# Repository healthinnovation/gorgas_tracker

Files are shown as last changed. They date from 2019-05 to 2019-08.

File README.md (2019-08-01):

# GORGAS tracker - Project: Malaria and Human Mobility in the Peruvian Amazon

The GORGAS tracker is an open-source GPS tracker developed by the [Health Innovation Lab](https://imtavh.cayetano.edu.pe/en/research/labs/health-innovation-laboratory.html) from The Institute of Tropical Medicine "Alexander von Humboldt". The GPS tracker was developed and used in a cohort study to investigate the role of human population movement in malaria epidemiology in rural villages in the Peruvian Amazon river networks.

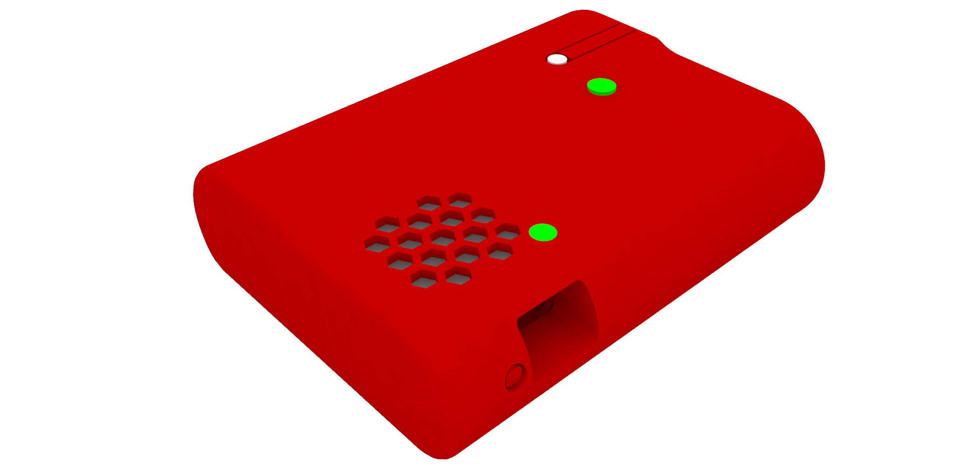
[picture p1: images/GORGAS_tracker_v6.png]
GORGAS tracker 3D model


The GORGAS tracker is based on the [Rephone](http://wiki.seeedstudio.com/RePhone/) platform (SeeedStudio) and has the following characteristics:
* Long-life battery
* Stores GPS coordinates and timestamp
* Sets a buffer area and report if a participant move outside that boundary
* Locks the interaction with the participant
* Easy set-up during fieldwork using a laptop/tablet (visual interface)

Are you ready to build your own GORGAS tracker?
* Hardware: Bill of materials and STL files
* Scripts: GORGAS tracker algorithms
* Visual Interface: PC/Tablet Visual Interface

Visualizacion_Mov

***Understanding the relationship between malaria transmission and human mobility in diverse endemic settings is key for designing and implementing locally adapted and sustainable control and elimination strategies*** (Rosa-Aguirre et al., 2017).

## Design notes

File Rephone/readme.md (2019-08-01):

# GORGAS tracker scripts
This repository contains the scripts that run the GORGAS tracker. This device is based on [Rephone Geo Kit](https://www.seeedstudio.com/RePhone-Geo-Kit-p-2624.html). Rephone is an open source modular phone that supports different integrated development environments (IDE): Lua, Javascript, Arduino IDE and Eclipse IDE. Our team worked with Arduino IDE.

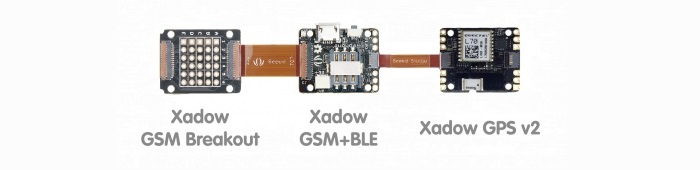
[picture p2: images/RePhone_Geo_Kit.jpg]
RephoneGeoKit


## Before you start
We recommend you to visit [Rephone wiki documentation](http://wiki.seeedstudio.com/RePhone/). There you will find information about [Arduino IDE for Rephone](http://wiki.seeedstudio.com/Arduino_IDE_for_RePhone_Kit/) version which contains the libraries you need to upload the code. Also you can go directly to SeeedStudio Github repository and download the [Arduino IDE](https://github.com/Seeed-Studio/Arduino_IDE_for_RePhone).

**Note:** The Arduino IDE for Rephone is only available for Windows XP/Vista/⅞/8.1. Other versions soon. 

## Scripts
Algorithms are based on three tasks: **GPS files reading**, **Power Management**, and **GPS-tracking logs**. GPS files contain the data and medata divided in four plain text files (.txt):
* locations.txt: GPS coordinates, timestamp, number of satellites, battery life status, and quality of the GPS signal
* id.txt: participant ID and location status (to identify and report if a participant move outside that boundary)
* perimeter.txt: centroid and radius of the community (to set a buffer area)
* time.txt: time interval and time for active and sleep modes

### Workflow
- **GPS files reading:** starts with algorithm reading the id file to switch the led (red or green) on as an initial state. Then, the time file is read to set up times for power management and the time interval for tracking.
- **Power management:** configures internal time and date variables from GPS data received. The code is always comparing the internal clock and date with the time and date collected from satellites system. If variables are correct, power management allows the control module to collect location and store data on the locations file. Power mode (time file) is read by the power management to switch data logger off or restore its operations.
- **GPS-tracking logs:** collects participants location during the follow-up and constantly verify if a participant is outside the village boundary. As result update the location status in the id file. 

We developed two script versions:
- Simplified version: Gorgas_Simplificado.ino 
- Extended version: Gorgas_Final.ino

The simplified version of the script is based on functions and to modify the code is easier than the extended version. 

**Note:** You must check [Xadow GSM+BLE](http://wiki.seeedstudio.com/RePhone_Lumi_Kit/#xadow-gsmble) specifications and libraries first, if you want to modify the scripts.

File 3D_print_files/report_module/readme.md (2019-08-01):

## Reporting module
In order to inspect the report of whether the participant had moved outside the boundaries of the community, a new module (RGB led and one button) and algorithm were designed. This reporting module was coupled to the extension module allowing interaction with the control module. 

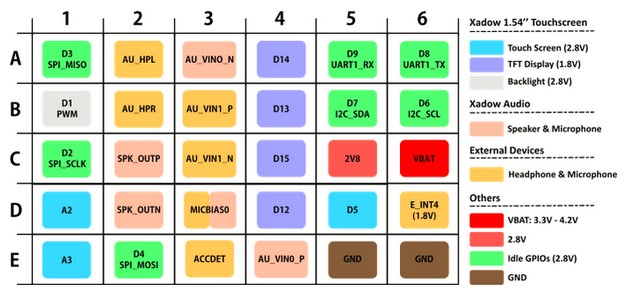
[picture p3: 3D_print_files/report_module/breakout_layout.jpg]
breakout_distribution


The colors distribution was red when the participant moved outside the boundaries, green when they were not registered movement outside the boundaries, and blue when incorrect GPS data was recorded at initialization. The button interaction distribution was one tap to verify whether the participant moved outside the boundary (red or green), and two taps to verify the correct initialization (blue).

### Electronic components
- Button (x1)
- RGB LED 5050 (x1)
- RES 330Ohm SMD (x1)
- Male pins (x5)

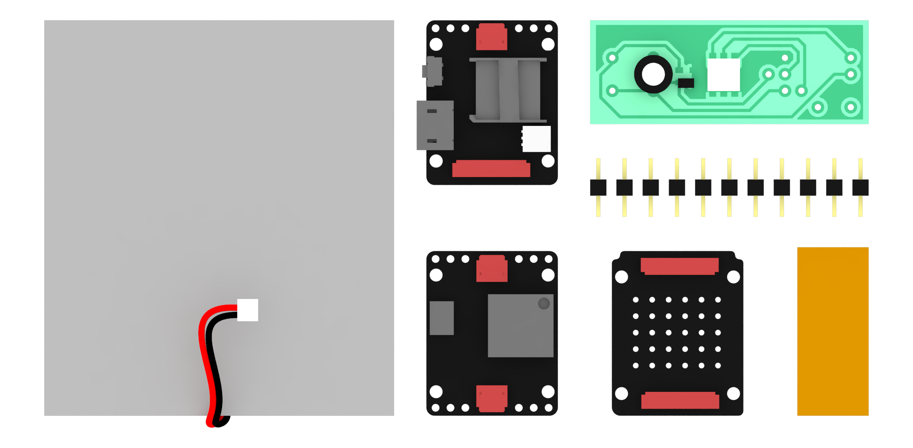
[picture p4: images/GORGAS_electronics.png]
electronics


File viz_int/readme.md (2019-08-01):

# GORGAS tracker visual interface v1.0
A graphic interface was developed on Visual Studio to visualize the datasets in a comprehensive way. The initial view was a menu with three options: GPS-tracker configuration, Map configuration and Data analysis. **Note:** The visual interface is only available in Spanish. English version soon.

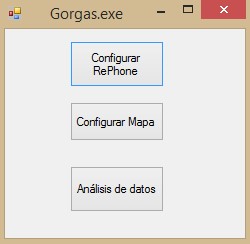
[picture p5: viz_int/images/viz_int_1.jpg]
main


GPS-tracker configuration was a section where user should select the connected device to upload a new configuration. This option has two ways to configure data loggers: default configuration and customized configuration. Default configuration has data from the last default or customized configuration. Customized configuration allows user to modify ID, latitude, longitude, radius of buffer (meters), time interval, active mode (time), and sleep mode (time).

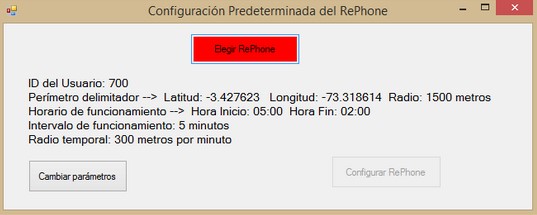
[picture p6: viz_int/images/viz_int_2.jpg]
configuration1


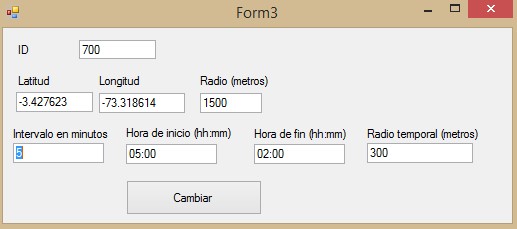
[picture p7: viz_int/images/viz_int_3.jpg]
configuration2


Map configuration was a section to store offline Google maps. Users had to select a specific area (e.g. province of Maynas) and then they could download the map with Internet and store it to computer memory. These maps were useful for data analysis in the field where connectivity is limited. 

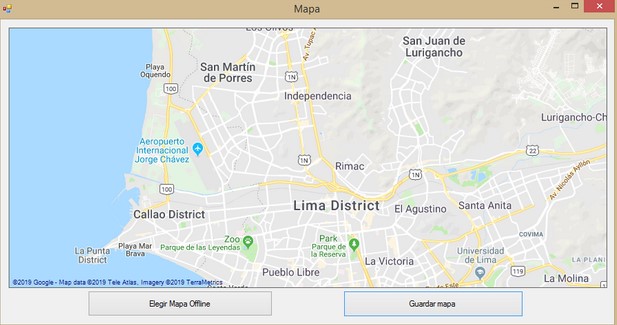
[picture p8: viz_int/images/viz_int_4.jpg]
map


The last option was Data analysis, a section to perform a preview data analysis on the field. Users could upload all GPS files on the graphic interface and they would see the offline map with location points stored and the GPS-tracker configuration. According research team needs, it was developed a functionality to simulate participants’ travels based on tracking data. The graphic interface proposed in this study is more suitable to field studies than traditional GIS software (e.g. preview datasets analysis or following study progression) but it doesn’t replace GIS for complex analysis.

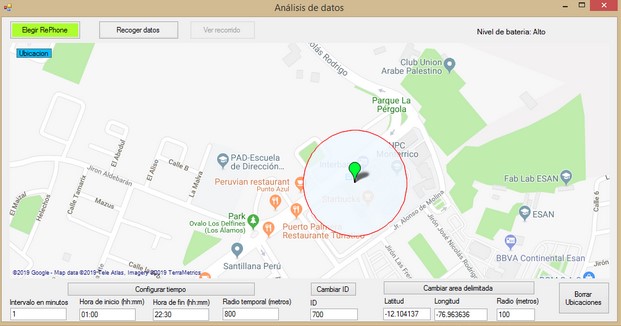
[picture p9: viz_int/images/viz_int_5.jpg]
data_analysis1


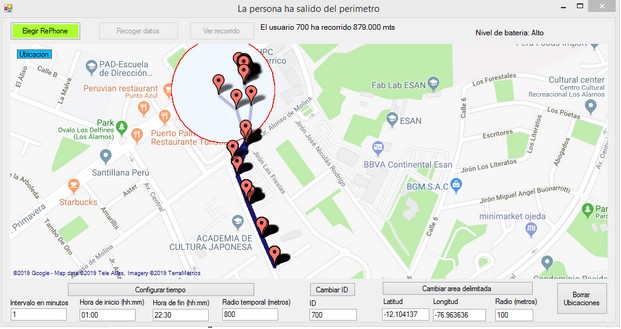
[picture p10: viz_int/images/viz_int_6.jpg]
data_analysis2


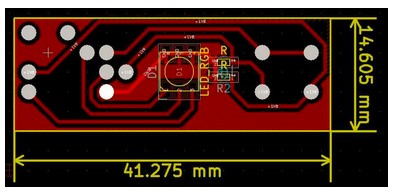
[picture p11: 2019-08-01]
3D_print_files/report_module/PCB_KiCAD.jpg

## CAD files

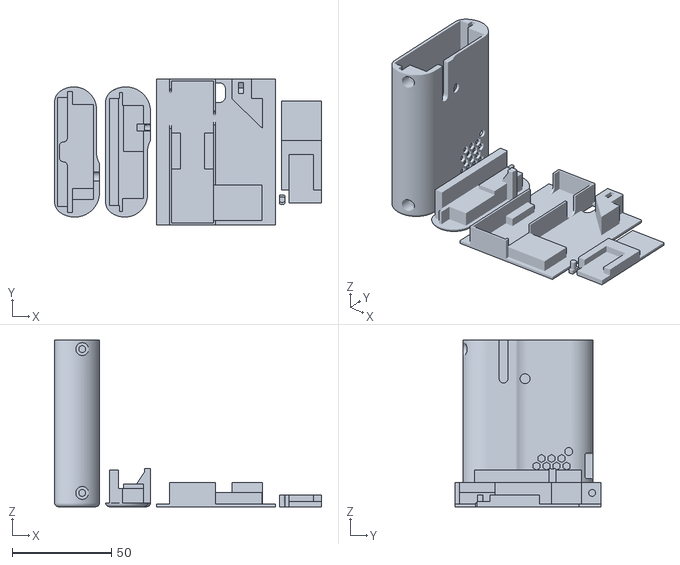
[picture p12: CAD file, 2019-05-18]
3D_print_files/Malaria v6.0.stl
134.8 x 73.8 x 84.1

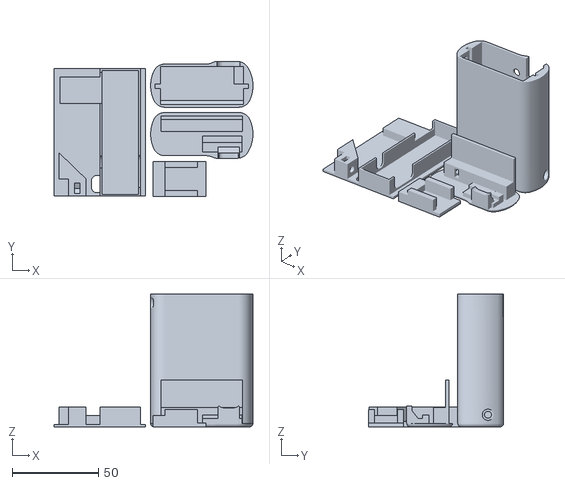
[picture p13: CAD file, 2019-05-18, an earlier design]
3D_print_files/Malaria v5.0.stl
115.2 x 78.2 x 76.8

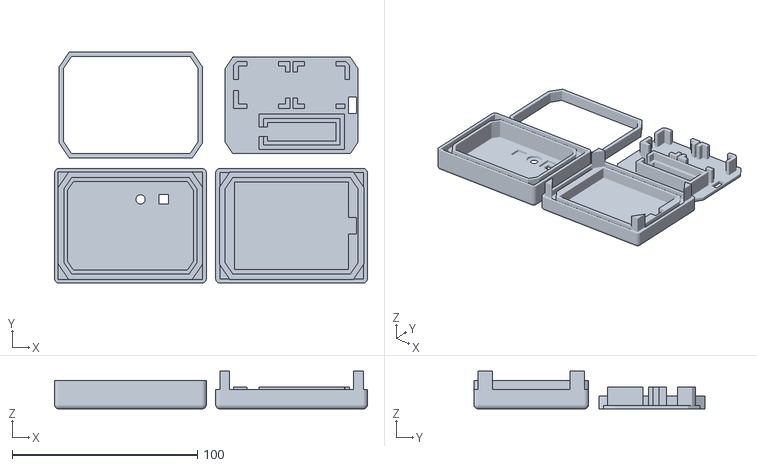
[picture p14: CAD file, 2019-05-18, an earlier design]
3D_print_files/Malaria v2.0.stl
169.0 x 124.9 x 20.5

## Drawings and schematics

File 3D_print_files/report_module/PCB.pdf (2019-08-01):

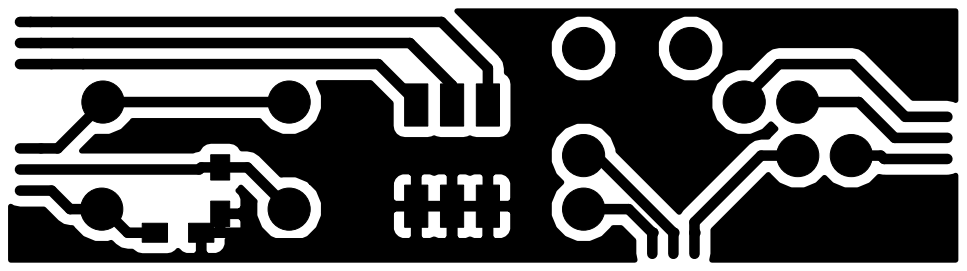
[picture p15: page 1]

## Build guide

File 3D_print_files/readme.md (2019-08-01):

# GORGAS tracker STL files
This folder is for STL files that have been compiled through the build process. Here you will find different GORGAS tracker versions that we think you could use them for other applications. 3D printed parts have been carefully designed to print reliably on most RepRap-style printers, without support material or adhesion layer. If your printer has a standard-sized bed (180mmx180mm should be fine) then it's possible to print the complete GORGAS tracker.

_Version 6.0 (65.73x22.75x86.10mm) was the last design and it was tested on urban and rural settings from Iquitos, Loreto (Peru)_

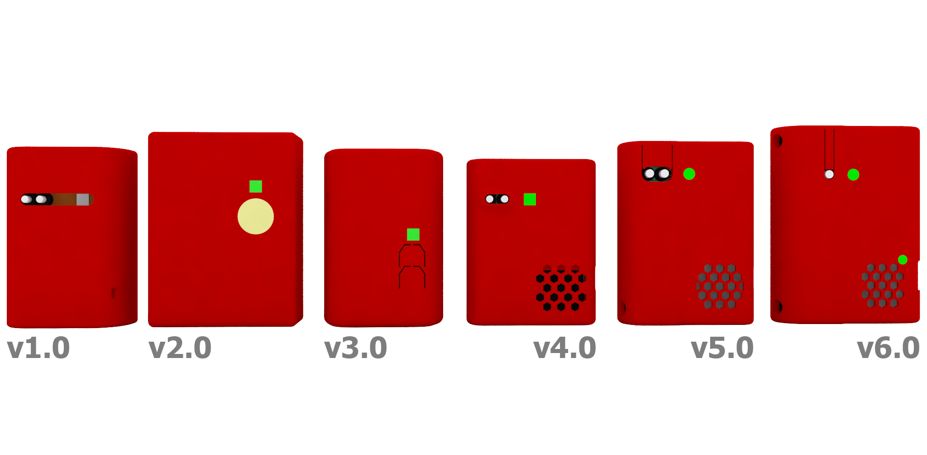
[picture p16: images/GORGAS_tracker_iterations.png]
GORGAS_tracker_iterations


## Print settings
* **3D Printer model:** Prusa i3 (reference)
* **Layer size:** 0.2mm
* **Adhesion type:** Brim (optional)
* **Support type:** None
* **Infill Density:** 30%
* **Filament:** PLA/ABS

STL_animation

## Bill of materials
* Rephone Geo Kit + Reporting module (x1)
* 3D printed parts set (x1)
* Li-Po battery 2500mAh (x1)
* M3 12mm screws (x2)
* M3 nuts (x2)

## Hardware assembly
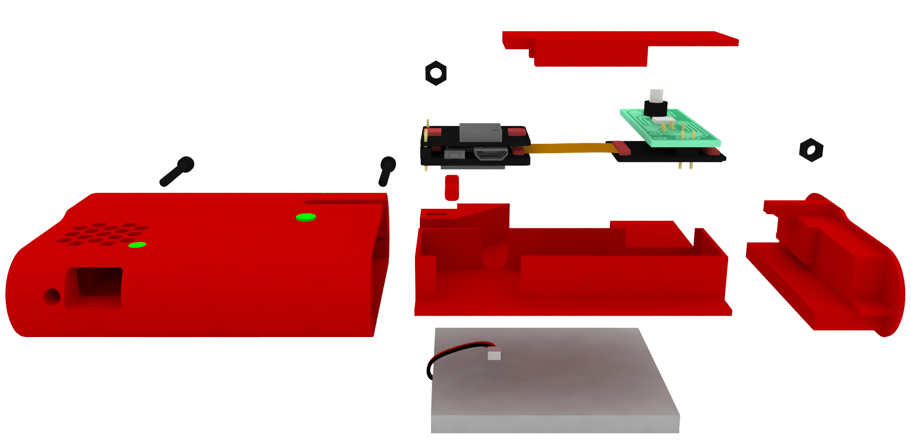
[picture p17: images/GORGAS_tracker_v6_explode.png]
GPS_explode


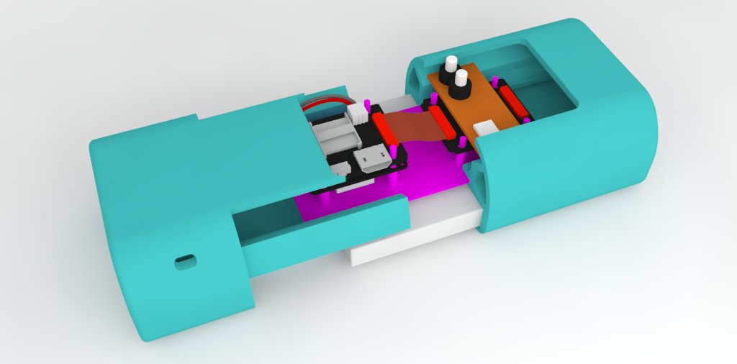
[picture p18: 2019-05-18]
3D_print_files/Malaria v1.0.jpg

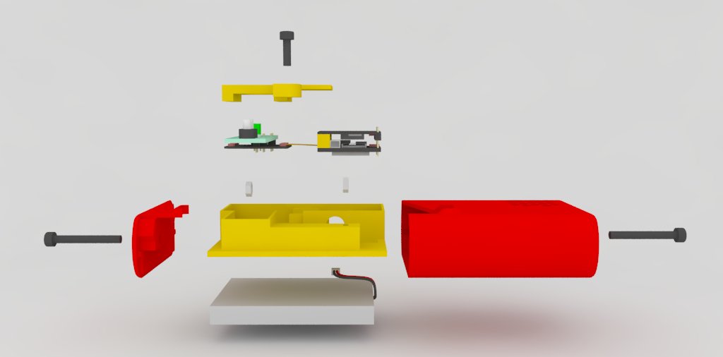
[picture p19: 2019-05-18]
3D_print_files/Malaria v4.0.jpg

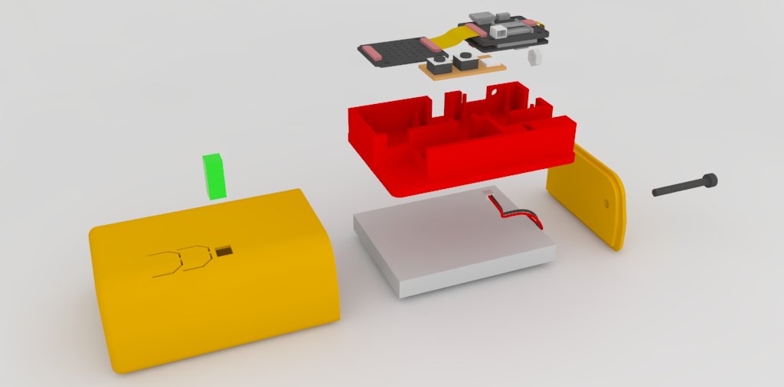
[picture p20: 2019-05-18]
3D_print_files/Malaria v3.0.jpg

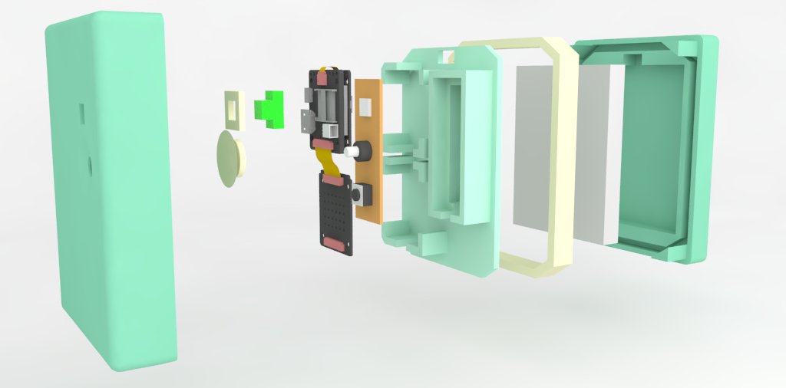
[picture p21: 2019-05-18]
3D_print_files/Malaria v2.0.jpg

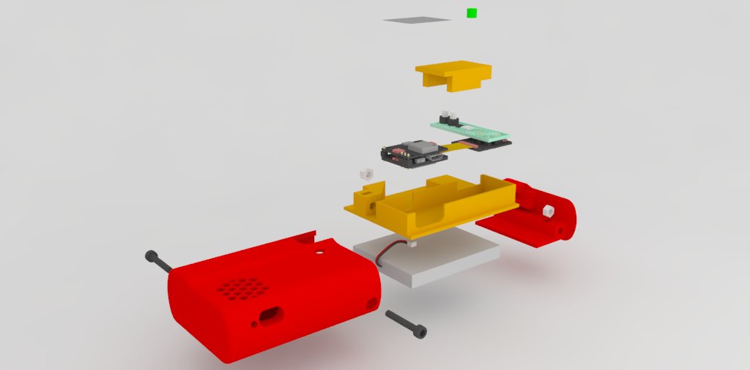
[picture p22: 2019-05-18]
3D_print_files/Malaria v5.0.jpg

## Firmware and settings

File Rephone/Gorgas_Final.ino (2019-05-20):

//Ubicacion
#include <LGPS.h>
#include <stdio.h>
//Fecha y almacenamiento de datos
#include <LCFile.h>
#include <LDateTime.h>
#include <LBattery.h>
datetimeInfo t; //Variable para establecer la fecha
int meses[12]= {31,28,31,30,31,30,31,31,30,31,30,31};
unsigned char *utc_date_time_i = 0; //Establece la comunicacion inicial con el GPS
//Pulsadores
#define GPIO_46 E4 //Boton 
//LED
#define LEDR  15 //GPIO_50  
#define LEDG  A3 //GPIO_02
#define LEDB  5 //GPIO_19 
#define    LED_B    16 //Rephone
#define    LED_G    17 //Rephone
#define    LED_R    18 //Rephone
#define    LED_ON     1
#define    LED_OFF    0
//Var
float lat = 0; //Float para ir almacenando la latitud provieniente del GPS
float lng = 0; //Float para ir almacenando la longitud proveniente del GPS
float latprevia = 0; //Float para almacenar la ultima latitud valida
float lngprevia = 0; //Float para almacenr la ultima longitud valida
char status; //Filtro para determinar la data correcta
int bat; //Valor actual de bateria del RePhone
double sat; //Numero de satelites captados
int fecha=0; //Bandera para verificar si se configuró la fecha
int ubicacion=0; //Bandera para verificar si se adquirió una ubicacion correcta
int encendido=0; //Bandera para verificar si esta en el rango de horas 
int reset=0; //En caso no responda el chip o el GPS
int data_incorrecta=1; //Contador de datos incorrectos
//Datos extraidos del txt perimetro 
float latcent = 0; 
float lngcent = 0; 
double radio = 0;
//Datos extraidos del txt tiempo
int inicio_min=0;
int inicio_hor=0;
int fin_min=0;
int fin_hor=0;
int frecuencia=0;
double desplazamiento = 0;
//Datos extraidos del txt id
char estado; //Avisa si la persona sale del perimetro
char id[10] = {0};

void setup() {
    attachInterrupt(GPIO_46,interruptServer,FALLING);
    //Serial.begin(9600);
    pinMode(LEDG, OUTPUT); 
    pinMode(LEDR, OUTPUT); 
    pinMode(LEDB, OUTPUT);
    pinMode(LED_B,OUTPUT);
    pinMode(LED_G,OUTPUT);
    pinMode(LED_R,OUTPUT);
    //Apago el led RGB
    digitalWrite(LEDG, LED_OFF);
    digitalWrite(LEDR, LED_OFF);
    digitalWrite(LEDB, LED_OFF);
    //Apago los leds del RePhone
    digitalWrite(LED_B,1);
    digitalWrite(LED_G,1);
    digitalWrite(LED_R,1);
    //Extraer data de los .txt
      char readdata[100] = {0};
      char aux_datos[10] = {0}; //Maximo 10 digitos
     //Extraer data de id
      LFile.Read("id.txt",readdata,100,0);
      for(int i=0; readdata[i] != ' ' && readdata[i] != '\r'  ;i++)
      {
        id[i] = readdata[i];
      }
      for(int i=0; i<sizeof(readdata);i++)
      {
        if(readdata[i] == ':')
        { 
          if(readdata[i+1] == ' ') i = i+1;
          estado = readdata[i+1];
        }
      }
      memset(readdata,0,sizeof(readdata));
    //Extraer data de tiempo
      LFile.Read("tiempo.txt",readdata,100,0);
      for(int i=0;readdata[i] != 'm'  ;i++)
      {
        if(readdata[i] == ':')
        {
          int cuenta = 0;
          if(readdata[i+1] == ' ') i=i+1;
          for(int j=i+1;readdata[j] != 'm';j++)
          {
            aux_datos[cuenta]=readdata[j];
            cuenta=cuenta+1;
          }
          break;
        }
      }
      frecuencia = atol(aux_datos);
      memset(aux_datos,0,sizeof(aux_datos));
      for(int i=0; i<100;i++)
      {
        if(readdata[i] == 'h' && readdata[i+11] == ':')
        {
         if(readdata[i+12] == ' ')i=i+1;
         aux_datos[0] = readdata[i+12];
         aux_datos[1] = readdata[i+13];
         inicio_hor = atol(aux_datos);
         aux_datos[0] = readdata[i+15];
         aux_datos[1] = readdata[i+16];
         inicio_min = atol(aux_datos);
         memset(aux_datos,0,sizeof(aux_datos));
        }
        else if(readdata[i] == 'h' && readdata[i+8] == ':')
        {
          if(readdata[i+9] == ' ')i=i+1;
         aux_datos[0] = readdata[i+9];
         aux_datos[1] = readdata[i+10];
         fin_hor = atol(aux_datos);
         aux_datos[0] = readdata[i+12];
         aux_datos[1] = readdata[i+13];
         fin_min = atol(aux_datos);
         memset(aux_datos,0,sizeof(aux_datos));
        }
        else if(readdata[i] == 'r' && readdata[i+5] == ':')
        {
          if(readdata[i+6] == ' ')i=i+1;
          int cuenta = 0;
          for(int j=i+6;readdata[j] != 'm' && readdata[j] != ' ';j++)
          {
             aux_datos[cuenta] = readdata[j];
             cuenta++;
          }
          desplazamiento = atof(aux_datos);
          memset(aux_datos,0,sizeof(aux_datos));
          break;
        }
      }
      memset(readdata,0,sizeof(readdata));
     //Extraer de perimetro
      LFile.Read("perimetro.txt",readdata,100,0);
      int ayuda = 0;
      for(int i=0;readdata[i] != 'm'  ;i++) 
      {
        if(readdata[i] == '-')
        {
          int contador=0;
          memset(aux_datos,0,sizeof(aux_datos));
          for(int j=i; readdata[j]!= ',' && readdata[j] != ' ' && readdata[j] != '\r' && readdata[j] != '\n' ;j++)
          {
            aux_datos[contador] = readdata[j];
            contador = contador + 1;
          }
          ayuda = ayuda + 1;
          if (ayuda == 1) latcent = atof(aux_datos);
          else if (ayuda == 2){ lngcent = atof(aux_datos); ayuda = 0;}
        } 
        else if(readdata[i] == 'R')
        {
          int contador=0;
          memset(aux_datos,0,sizeof(aux_datos));
          for(int j=i+7; readdata[j]!= ' ' && readdata[j] != 'm';j++)
          {
            aux_datos[contador] = readdata[j];
            contador = contador + 1;
          }
          radio = atof(aux_datos);
        }  
      }
      memset(readdata,0,sizeof(readdata));
    digitalWrite(LEDG, LED_ON);
    delay(5000);
    digitalWrite(LEDG,LED_OFF); 
    ///Configurar Hora y fecha al arranque
    if (LGPS.check_online())
    {
      utc_date_time_i = LGPS.get_utc_date_time();
      t.year  = utc_date_time_i[0];
      if((int)t.year > 17 && (int)t.year<30) 
      {
        t.mon   = utc_date_time_i[1];
        t.day   = utc_date_time_i[2];
        t.hour  =  utc_date_time_i[3] - 5;
        if(t.hour < 0) 
        {
          t.hour = t.hour+24;
          if(t.day == 1)
          {
            t.mon=t.mon-1;
            t.day=meses[t.mon-1];
          }
          else t.day = t.day-1;
        }
        t.min   =  utc_date_time_i[4];
        t.sec   = utc_date_time_i[5];
        fecha = 1;
        LDateTime.setTime(&t);
        LDateTime.getTime(&t);
        ////////////////////////////////////////////////////////////////////////AQUI INICIA EL CAMBIO
        if(inicio_hor < fin_hor)
        {
        	if(t.hour > inicio_hor) 
	  	{
			if(t.hour < fin_hor) encendido = 1;
			else if(t.hour > fin_hor) encendido = 0;
			else
			{
				if(t.min < fin_min) encendido = 1;
				else  encendido = 0;
			}
		}
		
		else if(t.hour < inicio_hor) encendido = 0;
		else
		{
			if(t.min >= inicio_min) encendido = 1;
			else  encendido = 0;
		}
        }

	else if(inicio_hor > fin_hor)
        {
        	if(t.hour > inicio_hor) encendido = 1;
		else if(t.hour < inicio_hor)
	  	{
			if(t.hour < fin_hor) encendido = 1;
			else if(t.hour > fin_hor) encendido = 0;
			else
			{
				if(t.min < fin_min) encendido = 1;
				else  encendido = 0;
			}
		}
		else
		{
			if(t.min >= inicio_min) encendido = 1;
			else  encendido = 0;
		}
        }

	else
	{
		if(inicio_min < fin_min)
		{
			if(t.hour != inicio_hor) encendido = 0;
			else
			{
				if(t.min < fin_min && t.min >= inicio_min) encendido = 1;
				else  encendido = 0;
			}
		}
		else
		{
			if(t.hour != inicio_hor) encendido = 1;
			else
			{
				if(t.min >= fin_min && t.min < inicio_min) encendido = 0;
				else  encendido = 1;
			}
		}
	}

        ////////////////////////////////////////////////////////////////////////AQUI ACABA EL CAMBIO
        lat = LGPS.get_latitude() * (-1);
        lng = LGPS.get_longitude();     
        lng = LGPS.get_longitude()*(-1);
        status = LGPS.get_status();
        sat = LGPS.get_sate_used();
        if(status == 'A' && lat != 0 && lng != 0)
        { 
          if(abs(lat)>90) lat = lat/100;
          if(abs(lng)>180) lng = lng/100; 
          double largo = 0;
          double ancho = 0;
          double distancia = 0;
          char writedata[200] = {0};
          largo= abs(lat - latcent)*111120;
          ancho= abs(lng - lngcent)*111120;
          distancia = sqrt(pow(largo,2)+pow(ancho,2));
          if(distancia < radio)//Si el primer dato esta dentro del perimetro
          {
              ubicacion = 1;
              latprevia = lat;
              lngprevia = lng;
                //Almaceno la primera data valida
                bat = LBattery.level();
                sprintf((char*)writedata, "Fecha:%d-%d-%i  %d:%d:%d Latitud:%f Longitud:%f Bateria:%i Satelites:%.1f Status:%c\r\n",t.day, t.mon,(int)t.year - 48,t.hour, t.min, t.sec, lat, lng,bat,sat,status);
                LFile.Write("ubicaciones.txt", writedata);
                estado = 'D';
                LFile.Create("id.txt");
                LFile.Write("id.txt", id);
                LFile.Write("id.txt","\r\nEstado: Dentro del perimetro\r\n");
                delay(1000*60*frecuencia); 
          }
          else 
          {
            lng = lng + 0.667 ;
            largo= abs(lat - latcent)*111120;
            ancho= abs(lng - lngcent)*111120;
            distancia = sqrt(pow(largo,2)+pow(ancho,2));
            if(distancia < radio)//Si el primer dato es dentro del perimetro
            {
              ubicacion = 1;
              latprevia = lat;
              lngprevia = lng;
                //Almaceno la primera data valida
                 bat = LBattery.level();
                sprintf((char*)writedata, "Fecha:%d-%d-%i  %d:%d:%d Latitud:%f Longitud:%f Bateria:%i Satelites:%.1f Status:%c\r\n",t.day, t.mon,(int)t.year - 48,t.hour, t.min, t.sec, lat, lng,bat,sat,status);
                LFile.Write("ubicaciones.txt", writedata);
                estado = 'D';
                LFile.Create("id.txt");
                LFile.Write("id.txt", id);
                LFile.Write("id.txt","\r\nEstado: Dentro del perimetro\r\n");
                delay(1000*60*frecuencia); 
            }
            else ubicacion = 0;
          }
        }
        else 
        {
          ubicacion = 0;
        }
      }
      else fecha=0;
     }
}

void loop() {
  while(fecha == 0) //Intenta hasta establecer la fecha
  {
    if (LGPS.check_online())
    {
      utc_date_time_i = LGPS.get_utc_date_time();
      t.year  = utc_date_time_i[0];
      if((int)t.year > 17 && (int)t.year < 30) 
      {
        t.mon   = utc_date_time_i[1];
        t.day   = utc_date_time_i[2];
        t.hour  =  utc_date_time_i[3] - 5;
        if(t.hour < 0) 
        {
          t.hour = t.hour+24;
          if(t.day == 1)
          {
            t.mon=t.mon-1;
            t.day=meses[t.mon-1];
          }
          else t.day = t.day-1;
        }
        t.min   =  utc_date_time_i[4];
        t.sec   = utc_date_time_i[5];
        fecha = 1;
        //Serial.println("Fecha configurada");
        LDateTime.setTime(&t);
      }
      else 
      {
        fecha=0;
        //Serial.println("Esperando fecha");
      }
    }
    delay(500);
  }
  
  if(fecha == 1)
  {                         
    Verificar_Encendido();
  }
  if(encendido == 1 && ubicacion == 1) //Dispositivo funcionando
  {
    GPS();
  } 
  while(ubicacion == 0)
  {
      Verificar_Encendido();///
      if (LGPS.check_online())
      {
        lat = LGPS.get_latitude() * (-1);
        lng = LGPS.get_longitude();
        lng = LGPS.get_longitude()*(-1);
        status = LGPS.get_status();
        sat = LGPS.get_sate_used();
        if(status == 'A' && lat != 0 && lng != 0)
        { 
          if(abs(lat)>90) lat = lat/100;
          if(abs(lng)>180) lng = lng/100; 
          double largo = 0;
          double ancho = 0;
          double distancia = 0;
          char writedata[200] = {0};
          largo= abs(lat - latcent)*111120;
          ancho= abs(lng - lngcent)*111120;
          distancia = sqrt(pow(largo,2)+pow(ancho,2));
          if(distancia < radio)//Si el primer dato esta dentro del perimetro
          {
              ubicacion = 1;
              latprevia = lat;
              lngprevia = lng;
                //Almaceno la primera data valida
                bat = LBattery.level();
                sprintf((char*)writedata, "Fecha:%d-%d-%i  %d:%d:%d Latitud:%f Longitud:%f Bateria:%i Satelites:%.1f Status:%c\r\n",t.day, t.mon,(int)t.year - 48,t.hour, t.min, t.sec, lat, lng,bat,sat,status);
                LFile.Write("ubicaciones.txt", writedata);
                estado = 'D';
                LFile.Create("id.txt");
                LFile.Write("id.txt", id);
                LFile.Write("id.txt","\r\nEstado: Dentro del perimetro\r\n");
                //Serial.print("Sin desfase ");
                //Serial.print(writedata);
          }
          else 
          {
            lng = lng + 0.667 ;
            largo= abs(lat - latcent)*111120;
            ancho= abs(lng - lngcent)*111120;
            distancia = sqrt(pow(largo,2)+pow(ancho,2));
            if(distancia < radio)//Si el primer dato es dentro del perimetro
            {
              ubicacion = 1;
              latprevia = lat;
              lngprevia = lng;
                //Almaceno la primera data valida
                bat = LBattery.level();
                sprintf((char*)writedata, "Fecha:%d-%d-%i  %d:%d:%d Latitud:%f Longitud:%f Bateria:%i Satelites:%.1f Status:%c\r\n",t.day, t.mon,(int)t.year - 48,t.hour, t.min, t.sec, lat, lng,bat,sat,status);
                LFile.Write("ubicaciones.txt", writedata);
                estado = 'D';
                LFile.Create("id.txt");
                LFile.Write("id.txt", id);
                LFile.Write("id.txt","\r\nEstado: Dentro del perimetro\r\n");
                //Serial.print("Con desfase ");
                //Serial.print(writedata);
            }
            else 
            {
                ubicacion = 0;
                //sprintf((char*)writedata, "Configurando A : %d-%d-%i  %d:%d:%d Latitud:%f Longitud:%f Satelites:%.1f Status:%c\r\n",t.day, t.mon,(int)t.year - 48,t.hour, t.min, t.sec, lat, lng,sat,status);
                //LFile.Write("ubicaciones.txt", writedata);
                //Serial.print("Data no valida ");
                //Serial.print(writedata);
            }
          }
        }
        else 
        {
          ubicacion = 0;
          //char writedata[200] = {0};
          //sprintf((char*)writedata, "Configurando V: %d-%d-%i  %d:%d:%d Latitud:%f Longitud:%f Satelites:%.1f Status:%c\r\n",t.day, t.mon,(int)t.year - 48,t.hour, t.min, t.sec, lat, lng,sat,status);
          //LFile.Write("ubicaciones.txt", writedata);
          //Serial.print("Data no valida ");
          //Serial.print(writedata);
        }
      }
      else ubicacion = 0;
      delay(500);
  }
  delay(1000*60*frecuencia); 
}
void interruptServer()
{
  if(fecha == 0 && ubicacion == 0)
  {
      digitalWrite(LEDG, LED_ON);
      digitalWrite(LEDR, LED_ON);
      digitalWrite(LEDB, LED_ON);
      delay(3000); //Encendido 3 segundos 
      digitalWrite(LEDR, LED_OFF);
      digitalWrite(LEDG, LED_OFF);
      digitalWrite(LEDB, LED_OFF);
  }
  else if(fecha == 1 && ubicacion == 1) //Dispositivo funcionando
  {
     if(estado == 'F') //Persona salió del perimetro
     {
       if(encendido == 1)///
       {//
       digitalWrite(LEDB, LED_OFF);
       digitalWrite(LEDG, LED_OFF);
       digitalWrite(LEDR, LED_ON);
       delay(3000); //Encendido 3 segundos 
       digitalWrite(LEDR, LED_OFF);
       } ///
       ////
       else { 
       digitalWrite(LEDB, LED_OFF);
       digitalWrite(LEDG, LED_OFF);
       digitalWrite(LEDR, LED_ON);
       delay(1000);
       digitalWrite(LEDB, LED_OFF);
       digitalWrite(LEDG, LED_OFF);
       digitalWrite(LEDR, LED_OFF);
       delay(1000);
       digitalWrite(LEDB, LED_OFF);
       digitalWrite(LEDG, LED_OFF);
       digitalWrite(LEDR, LED_ON);
       delay(1000); 
       digitalWrite(LEDR, LED_OFF);}
       ////

     }
     else if(estado == 'D') //Persona no salió del perimetro
     { 
       if(encendido == 1) ////
       {///
       digitalWrite(LEDR, LED_OFF);
       digitalWrite(LEDG, LED_ON);
       digitalWrite(LEDB, LED_OFF);
       delay(3000); //Encendido 3 segundos 
       digitalWrite(LEDG, LED_OFF);
       }///
        ////
       else { 
       digitalWrite(LEDB, LED_OFF);
       digitalWrite(LEDR, LED_OFF);
       digitalWrite(LEDG, LED_ON);
       delay(1000);
       digitalWrite(LEDB, LED_OFF);
       digitalWrite(LEDR, LED_OFF);
       digitalWrite(LEDG, LED_OFF);
       delay(1000);
       digitalWrite(LEDB, LED_OFF);
       digitalWrite(LEDR, LED_OFF);
       digitalWrite(LEDG, LED_ON);
       delay(1000); 
       digitalWrite(LEDG, LED_OFF);}
       ////
    }
  }
  else if(fecha == 1)
  {
        if(encendido == 1) ///
        { ///
       digitalWrite(LEDG, LED_OFF);
       digitalWrite(LEDR, LED_OFF);
       digitalWrite(LEDB, LED_ON);
       delay(3000); //Encendido 3 segundos 
       digitalWrite(LEDB, LED_OFF);
        }////
       ////
       else { 
       digitalWrite(LEDR, LED_OFF);
       digitalWrite(LEDG, LED_OFF);
       digitalWrite(LEDB, LED_ON);
       delay(1000);
       digitalWrite(LEDR, LED_OFF);
       digitalWrite(LEDG, LED_OFF);
       digitalWrite(LEDB, LED_OFF);
       delay(1000);
       digitalWrite(LEDR, LED_OFF);
       digitalWrite(LEDG, LED_OFF);
       digitalWrite(LEDB, LED_ON);
       delay(1000); 
       digitalWrite(LEDB, LED_OFF);}
       ////
  }
}

void GPS()
{
  char writedata[200] = {0};
  double largo = 0;
  double ancho = 0;
  double distancia = 0;
  reset = 0;
  while (LGPS.check_online() != 1) //Hasta que obtengas respuesta del GPS
  {
    reset=reset+1;
    delay(100);
    if(reset == 100)
    {  
      break;
    }
  }
  if(reset == 100) //Watchdog
  { 
    LDateTime.getTime(&t);
    bat = LBattery.level();
    sprintf((char*)writedata, "GPS no enciende hoy %d-%d-%i  %d:%d:%d Bateria:%i\r\n",t.day, t.mon,(int)t.year - 48,t.hour, t.min, t.sec,bat);
    LFile.Write("ubicaciones.txt", writedata);
  }
  else
  {
    for(int i=0;i<10;i++)
    {
      //
      lat = LGPS.get_latitude() * (-1);
      lng = LGPS.get_longitude();
      lng = LGPS.get_longitude() * (-1);
      status = LGPS.get_status();
      sat = LGPS.get_sate_used(); 
      if(status == 'A' && lat != 0 && lng != 0)
      { 
        if(abs(lat)>90) lat = lat/100;
        if(abs(lng)>180) lng = lng/100; 
        largo= abs(lat - latprevia)*111120;
        ancho= abs(lng - lngprevia)*111120;
        distancia = sqrt(pow(largo,2)+pow(ancho,2));
        if(distancia < desplazamiento*frecuencia*data_incorrecta)//Data valida en base a la ultima data aceptada
        {
          latprevia = lat;
          lngprevia = lng;
          data_incorrecta = 1;
          break;
        }
        else
        {
          lng = lng + 0.667;
          largo= abs(lat - latprevia)*111120;
          ancho= abs(lng - lngprevia)*111120;
          distancia = sqrt(pow(largo,2)+pow(ancho,2));
          if(distancia < desplazamiento*frecuencia*data_incorrecta)//Data valida en base a la ultima data aceptada
          {
            latprevia = lat;
            lngprevia = lng;
            data_incorrecta = 1;
            break;
          }
          else
          {
            if(i == 9) data_incorrecta++;
          }
        }
      }
      else 
      {
        if(i == 9) data_incorrecta++;
      }  
      delay(500);
      //
    }
    LDateTime.getTime(&t);
    if(data_incorrecta == 1)//Si recibi un dato correcto
    { 
      bat = LBattery.level();
      sprintf((char*)writedata, "Fecha:%d-%d-%i  %d:%d:%d Latitud:%f Longitud:%f %Bateria:%i Satelites:%.1f Status:%c\r\n",t.day, t.mon,(int)t.year - 48,t.hour, t.min, t.sec, lat, lng,bat,sat,status);
       LFile.Write("ubicaciones.txt", writedata);  
       Analizar_Data_Perimetro(lat,lng);
    }
    else 
    {
      bat = LBattery.level();
      sprintf((char*)writedata, "Mala cobertura fecha:%d-%d-%i  %d:%d:%d Latitud:%f Longitud:%f Bateria:%i Satelites:%.1f Status:%c\r\n",t.day, t.mon,(int)t.year - 48,t.hour, t.min, t.sec, lat, lng,bat,sat,status);
      LFile.Write("ubicaciones.txt", writedata);
    }
  }
  reset=0;
}
void Analizar_Data_Perimetro(float lat,float lng)
{
     double largo = 0;
     double ancho = 0;
     double distancia = 0;
     //Algoritmo de deteccion salida perimetro
     largo= abs(lat - latcent)*111120;
     ancho= abs(lng - lngcent)*111120;
     distancia = sqrt(pow(largo,2)+pow(ancho,2));
     if(distancia > radio) 
     {
      estado = 'F';
      LFile.Create("id.txt");
      LFile.Write("id.txt", id);
      LFile.Write("id.txt","\r\nEstado: Fuera del perimetro\r\n");
     }
     else if(distancia <= radio && estado != 'F')
     {
        estado = 'D';
        LFile.Create("id.txt");
        LFile.Write("id.txt", id);
        LFile.Write("id.txt","\r\nEstado: Dentro del perimetro\r\n");
     }
}
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

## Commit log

2019-05-18 GORGAS tracker STL files
2019-08-01 STL files and BOM
